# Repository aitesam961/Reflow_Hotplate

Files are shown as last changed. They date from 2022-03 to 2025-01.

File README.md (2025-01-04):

# Reflow_Hotplate

### Dear Community! 
Thanks for your interest in this project. We would like to inform you that we have noticed some bugs in the hardware part of this project. We cannot promise immediate support but we plan on fixing it as soon as we get time out of our living jobs. 
Appreciated 

<p align="center">
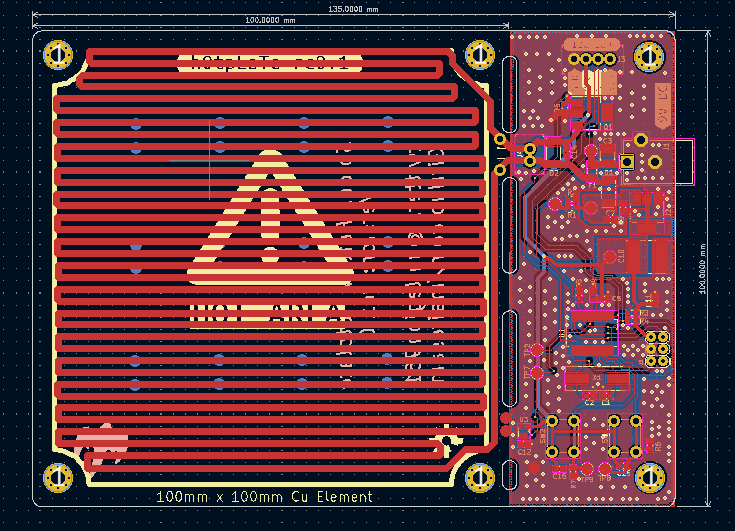
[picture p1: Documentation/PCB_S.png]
Opening Image
  
</p>
A reflow Hotplate for DIY SMD assembly.

## Introduction;
This device is created as a Low-Cost solution for DIY reflow assembly of SMD components. 

## Key Features:

* Compact Design
* 9V-12V DC Input via regular DC Jack 
* 100mm x 100mm Reflow area
* High-Current protection
* PIC16F MCU to control the system
* PIC programmer Interface
* I2C LCD Support
* Detachable design [See More](https://github.com/maitesam/Reflow_Hotplate/#detachable-design)
* Temperature Probs
* UI with LCD and Pushbuttons for controlling the system.
* Low Cost & Portable

<p align="center">
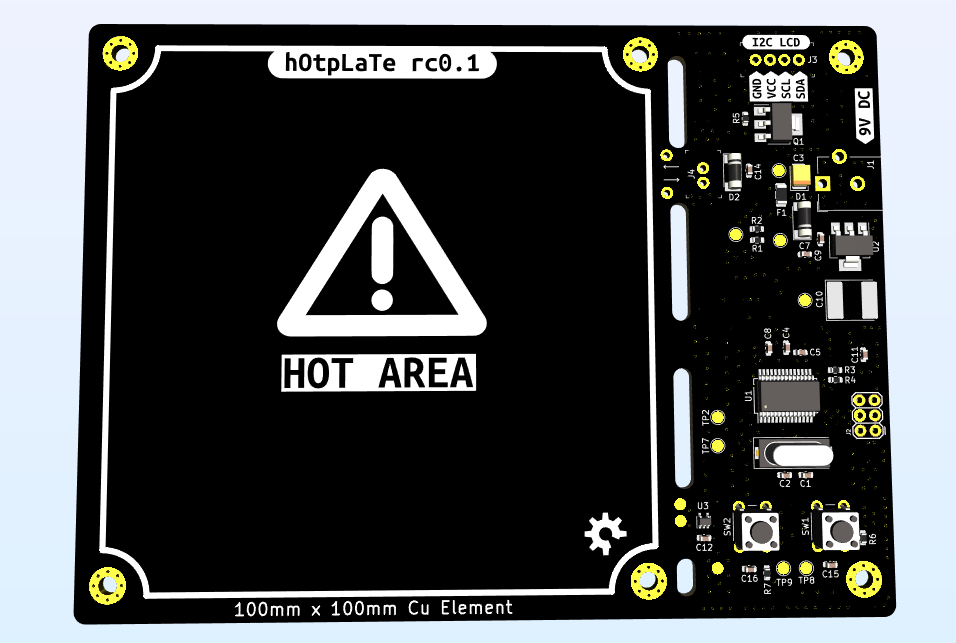
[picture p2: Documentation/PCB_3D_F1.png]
  
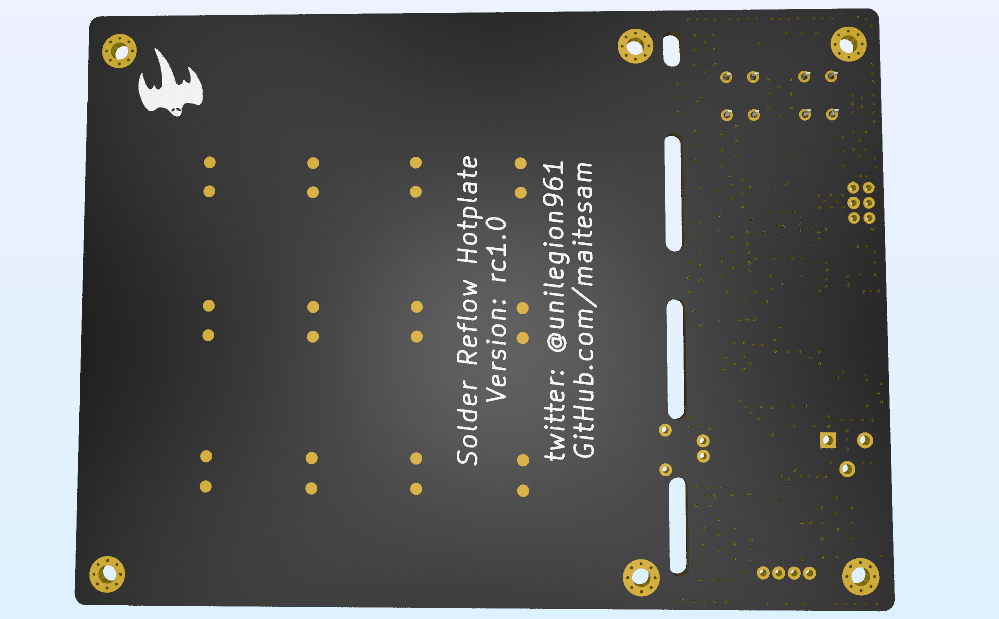
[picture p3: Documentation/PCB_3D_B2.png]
  
 
</p>

### What is Reflow Soldering?

Reflow soldering is a process in which a solder paste (a sticky mixture of powdered solder and flux) is used to temporarily attach one or thousands of tiny electrical components to their contact pads, after which the entire assembly is subjected to controlled heat. The solder paste reflows in a molten state, creating permanent solder joints. Heating may be accomplished by passing the assembly through a reflow oven.

[View more on Wikipedia](https://en.wikipedia.org/wiki/Reflow_soldering#:~:text=Reflow%20soldering%20is%20a%20process%20in%20which%20a,in%20a%20molten%20state%2C%20creating%20permanent%20solder%20joints)

### Reflow Curve
The reflow curve of the temperature of a certain point on the SMA with time when the SMA passes through the reflow oven furnace. The temperature curve provides an intuitive method to analyze the temperature change of a component during the entire reflow soldering process.
Below is the proper reflow curve a heater should achieve for perfect soldering of components.

The hOtpLaTe r0.1 manages to acheive this temperature curve by adjusting the switching duty of MOSFET which results in variation in heat.
The temperature sensor continously reads the temperatures and sends back to the Microcontroller.
<p align="center">
  Opening Image
</p>

### Detachable Design:
 This board is created considering all the potential issues and major use cases. The advantange is that you can use it either as a whole system by simply plugging the power in and starting the system
 OR
 You can detach the controller and Coil area of the PCB (separated by cut-lines).
 
 This makes it highly portable and Tweakers friendly.

 ### Why you may need to do this?
 The standard PCB material is FR4 which is very reliable in handling higher temperatures but it may not be very long lasting if being used very often.
 So, I came up with a backup plan and designed it in a way you can just cut the controller portion away from the coil area and use the controller with any OFF the SHELF heating element like alluminum plates.
 
 [Something Like This](https://www.aliexpress.com/item/1005003750400097.html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)

## Manufactruring Guidelines
You Can manufacture the PCBs from PCBWay.
[Check Out PCBWay](https://www.pcbway.com/setinvite.aspx?inviteid=440401)

Note: I am not affiliated with PCBWay. However, I just like their service and build quality.

## Assembly
It is super convenient to assemble the Hardware & Components specially if you ordered the Stencil alongwith PCBs.
After opening the Project in KiCAD, you can just scroll through the BOM and place components with respect to their designators.
OR
If you wish to order assembled PCBs, I optimized the BOM to make it super smooth and easy to source components. 
It is requested to please Open up an Issues if there is any stock outage or Manufacturing Problems.

## General Instructions
* Program the Microcontroller using CP210x/CH340x/FTDI based USB to serial converters.
* The ARDUINO IDE can be used to Program the Microcontroller.
* Power Up the Board using a PSU with 6-12V @ 2A Ratings.
*  Give Hotplate Enough time to Heatup and cooldown. Any Forced Cooldown solution is highly **NOT RECOMMENDED** as it reduces the Life of FR4 material.
* If Temperatures Higher than 270C are desired, feel free to breakdown/cutdown the Controller portion and Heating Element to avoid controller assembly meltdown. (In such case, desolder the Temperature sensor and extend it to the bottom of the hotplate using wires).

### Contributions

Contributions are what make the open source community such an amazing place to learn, inspire, and create. Any contributions you make are **greatly appreciated**.

If you have a suggestion that would make this better, please fork the repo and create a pull request. You can also simply open an issue with the tag "enhancement".
Don't forget to give the project a star! Thanks again!

1. Fork the Project
2. Create your Feature Branch (`git checkout -b feature/AmazingFeature`)
3. Commit your Changes (`git commit -m 'Add some AmazingFeature'`)
4. Push to the Branch (`git push origin feature/AmazingFeature`)
5. Open a Pull Request

## Roadmap
* [x] Proof of Concept
* [x] Research & Information
* [x] Finalizing The Idea
* [x] Schematics
* [x] PCB Design
* [x] Firmware Development
* [ ] Validation & Testing
* [x] Documentation
* [ ] Future Improvements

## Future Plans
This Hotplate is based on Regular FR4 materials that degrade over time due to excessive heating. In near future, it is desired to implement the same Idea on Alluminum Base PCBs. 
ISSUE: Alluminum would act as heatsink not letting the plate to heatup/quick cooldowns.
Community please step in.........

## License

This Project and information is published under General Public License V3.0 See `LICENSE.txt` for more information.
> https://www.gnu.org/licenses/quick-guide-gplv3.html

<p align="right">(<a href="#top">back to top</a>)</p>

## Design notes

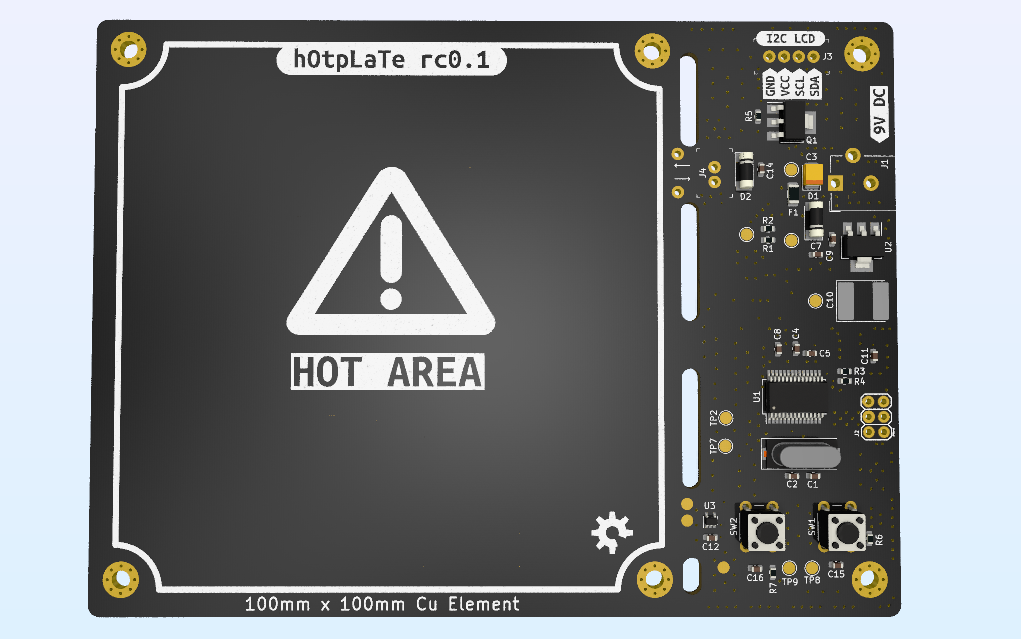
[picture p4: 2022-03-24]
Documentation/PCB_3D_F3.png

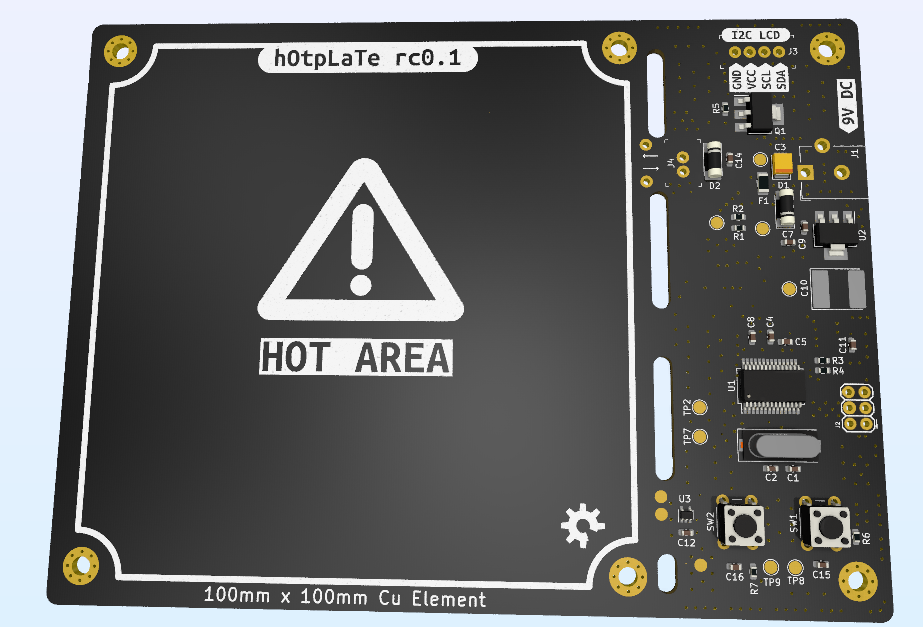
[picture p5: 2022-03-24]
Documentation/PCB_3D_F2.png

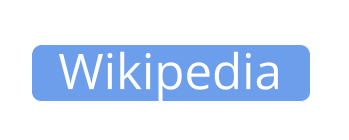
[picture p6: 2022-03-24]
Documentation/WIkipedia Button (1).png

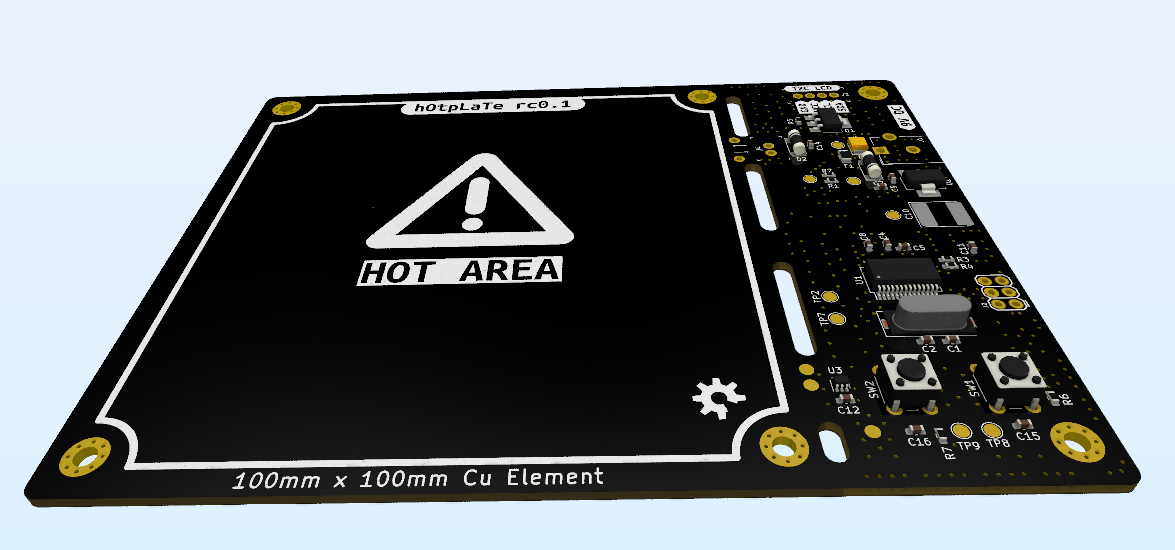
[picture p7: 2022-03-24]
Documentation/PCB_3D_F4.png

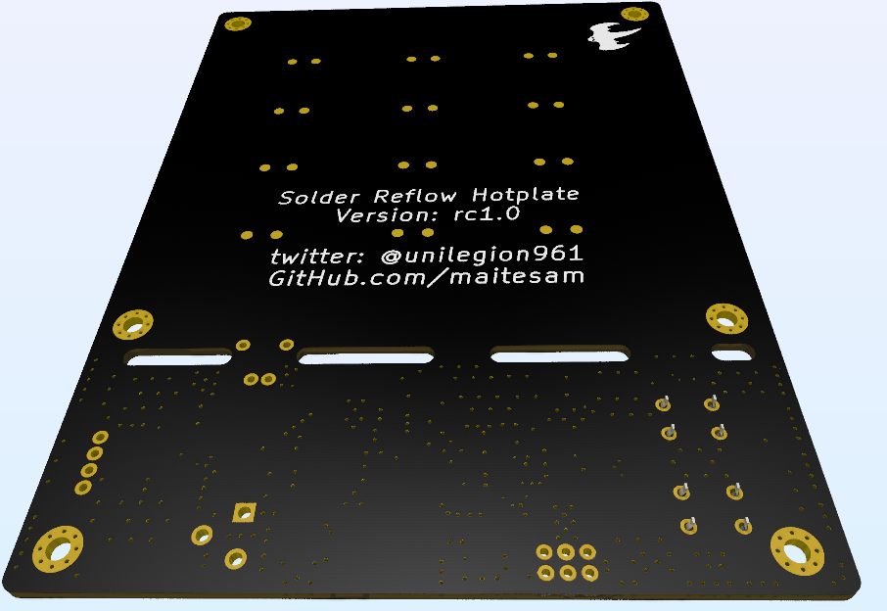
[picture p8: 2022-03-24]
Documentation/PCB_3D_B1.png

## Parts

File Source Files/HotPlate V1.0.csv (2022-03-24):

Source: | C:\Users\aites\Documents\KiCad\HotPlate V1.0\HotPlate V1.0.kicad_sch
Date: | 3/24/2022 1:29:14 AM
Tool: | Eeschema (6.0.4)
Generator: | D:\D_Program Files\6.0\bin\scripting\plugins/bom_csv_grouped_by_value_with_fp.py
Component Count: | 43
Ref | Qnty | Value | Cmp name | Footprint | Description | Vendor
C1, C2, C5, C8, C11, C12, C14, C15, C16, | 9 | 100nF | C_Small | Capacitor_SMD:C_0603_1608Metric | Unpolarized capacitor, small symbol
C3, | 1 | 10uF | C_Polarized_Small_US | Capacitor_Tantalum_SMD:CP_EIA-3528-12_Kemet-T | Polarized capacitor, small US symbol
C4, C7, C9, | 3 | 1uF | C_Small | Capacitor_SMD:C_0603_1608Metric | Unpolarized capacitor, small symbol
C10, | 1 | 22uF | C_Small | Capacitor_Tantalum_SMD:CP_EIA-7260-28_AVX-M_Pad2.68x6.30mm_HandSolder | Unpolarized capacitor, small symbol
D1, D2, | 2 | 1N5711UR | 1N5711UR | Diode_SMD:D_MELF | 70V 33mA Schottky diode, MELF(DO-213AA)
F1, | 1 | 2A | Fuse | Fuse:Fuse_1206_3216Metric | Fuse
J1, | 1 | Jack-DC | Jack-DC | Connector_BarrelJack:BarrelJack_CUI_PJ-102AH_Horizontal | DC Barrel Jack
J2, | 1 | CONN_03X22X3_SILK_MALE_PTH | CONN_03X22X3_SILK_MALE_PTH | Connectors:2X3 | Multi connection point. Often used as Generic Header-pin footprint for 0.1 inch spaced/style header connections <b>You can populate with any combo of single row headers, but if you'd like an exact match, check these:</b><ul><li><a href="https://www.sparkfun.com/products/12807"> Header - 2x3 (Male, 0.1")</a> (PRT-12807)</li><li><a href="https://www.sparkfun.com/products/13010"> Header - 2x3 (Female, 0.1")</a> (PRT-13010)</li><li><a href="https://www.sparkfun.com/products/10877"> 2x3 Pin Shrouded Header</a> (PRT-10877)</li></ul> <b>On any of the 0.1 inch spaced packages, you can populate with these:</b><ul><li><a href="https://www.sparkfun.com/products/116"> Break Away Headers - Straight</a> (PRT-00116)</li><li><a href="https://www.sparkfun.com/products/553"> Break Away Male Headers - Right Angle</a> (PRT-00553)</li><li><a href="https://www.sparkfun.com/products/115"> Female Headers</a> (PRT-00115)</li><li><a href="https://www.sparkfun.com/products/117"> Break Away Headers - Machine Pin</a> (PRT-00117)</li><li><a href="https://www.sparkfun.com/products/743"> Break Away Female Headers - Swiss Machine Pin</a> (PRT-00743)</li></ul> <b>Special note: the shrouded connector mates well with our 3x2 ribbon cables:</b><ul><li><a href="https://www.sparkfun.com/products/10651"> Ribbon Crimp Connector - 6-pin (2x3, Female)</a> (PRT-10651)</li><li><a href="https://www.sparkfun.com/products/10646"> Ribbon Cable - 6 wire (15ft)</a> (PRT-10646)</li></ul>
J3, | 1 | B4B-XH-A_LF__SN_ | B4B-XH-A_LF__SN_ | digikey-footprints:PinHeader_1x4_P2.5mm_Drill1.1mm | CONN HEADER VERT 4POS 2.5MM
J4, | 1 | B2B-XH-A_LF__SN_ | B2B-XH-A_LF__SN_ | digikey-footprints:PinHeader_1x2_P2.5mm_Drill1.1mm | CONN HEADER VERT 2POS 2.5MM
Q1, | 1 | DMG1012T | DMG1012T | Package_TO_SOT_SMD:SOT-223 | 20V Vds, 0.63 Id, N-Channel MOSFET with ESD protection, SOT-523
R1, | 1 | 3k | R_Small | Resistor_SMD:R_0603_1608Metric | Resistor, small symbol
R2, | 1 | 1k | R_Small | Resistor_SMD:R_0603_1608Metric | Resistor, small symbol
R3, R4, R5, R6, R7, | 5 | 10k | R_Small | Resistor_SMD:R_0603_1608Metric | Resistor, small symbol
SW1, SW2, | 2 | SW_Push | SW_Push | Button_Switch_THT:SW_PUSH_6mm | Push button switch, generic, two pins
TP1, TP2, TP3, TP4, TP6, TP7, TP8, TP9, | 8 | TestPoint | TestPoint | TestPoint:TestPoint_Pad_D2.0mm | test point
U1, | 1 | PIC16F1512-ISS | PIC16F1512-ISS | Package_SO:SSOP-28_5.3x10.2mm_P0.65mm | PIC16F1512, 2048W FLASH, 128B SRAM, SSOP-28
U2, | 1 | AMS1117-5.0 | AMS1117-5.0 | Package_TO_SOT_SMD:SOT-223-3_TabPin2 | 1A Low Dropout regulator, positive, 5.0V fixed output, SOT-223
U3, | 1 | LMT85DCK | LMT85DCK | Package_TO_SOT_SMD:SOT-353_SC-70-5 | Analog temperature sensor, NTC, 0.3C accuracy, -8.2mV/C, -50C to +150C, 1.8 to 5.5V, SC-70-5
X1, | 1 | 16MHz | Crystal | Crystal:Crystal_SMD_HC49-SD | Two pin crystal

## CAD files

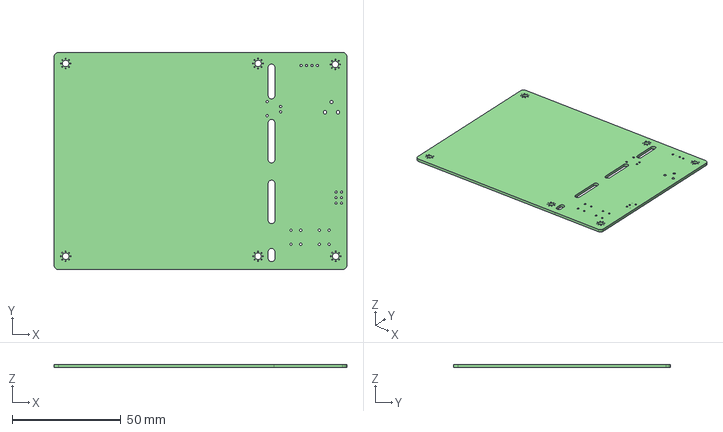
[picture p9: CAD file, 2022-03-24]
Manufacturing Files/HotPlate V1.0.step
135.0 x 100.0 x 1.60 mm

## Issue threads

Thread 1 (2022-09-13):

Power transitor issues (Q1)

saper-2, 2022-09-13:
I have basically 2 things to point out aroung Q1:

1. DMG1012T is in SOT-523 footprint, not in SOT-223 , 👉  fix P/N in schematic.
2. SOT-223 pin 4 "tab" should be connected to GND too, and around there should be some via for thermal dissipation to both GND zones.

aitesam961, 2022-09-13:
Eagle Eye Spotting.
Will work on fixing it soon.

aitesam961, 2022-09-13:
Invalid

Triton2020, 2022-11-27:
Hi, what is the Stand for this Fix ? I see no change on the PCB layout, what means your respond on thios Problem "Invalid" ???????

Triton2020, 2022-12-03:
It is not realy a Hint "check Source File" please can you explain what is the point ????

arrowsmashing, 2023-05-04:
Is there a recomended replacement part for Q1, have a DMG1012T-7, but it is too small to fit the pads?

Closed 2022-09-13.

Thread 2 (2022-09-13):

Thermal relief on pads connected to zone

saper-2, 2022-09-13:
Hi,

You don't have thermal relief on pads that connect to GND zone(s). It make much harder to solder parts, especially when it's not needed in 99,9% of them to have direct-connect style. Only in Q1 it desirable to use direct-connect style. In others parts not really. For small part 10-20mils wide, and 10mils margin from pad is fine. For e.g. components "bigger" like electrolytic capacitors or power jack 20-30mils width (10mils spacing too) should be fine in this circuit.

aitesam961, 2022-09-13:
Invalid

Closed 2022-09-13.

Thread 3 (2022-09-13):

Other suggestions

saper-2, 2022-09-13:
And few other suggestions 😄

1. When drawing slots for milling it's easier for fab just by drawing a line (track) on mechanical layer (that have width of mill bit diameter (mostly common bit sizes used by fab house have: 2mm and 3mm ) , so there is no need for wasting time to draw outline 😉 .
I use some User..... layer for this, and also I draw one in margin-layer (edge.cuts). Of course I leave note for fab house that on this layer is mill drawing.
2. U3 is a bit in unfortunate place 😉 , it's not directly on hot-plate section , and it "cooled down" by GND zones... since you're have milling already maybe think about something to make it "separable" in case if someone decide to brake apart board into control and hot-plate part. maybe mill a bit around it (using 2mm bit?) so more heat transfer from hot-plate part, and will be cooled less by control-circuit-part
3. Have you considered creating hot-plate using MCPCB (pcb aluminum , like the one used in power-led modules as radiator 😄 ). And I see JLC have rather acceptable price for it too.

aitesam961, 2022-09-13:
Invalid

Closed 2022-09-13.

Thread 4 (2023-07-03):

Arduino IDE

arrowsmashing, 2023-07-03:
Could you give some hints on the settings to use in Arduino IDE to upload the arduino.h to the PIC? E.g. what board to use in the settings?

aitesam961, 2023-07-09:
You can follow this guide on Instructables
https://www.instructables.com/how-to-program-a-PIC-18F2550-or-18f4550-with-Ardui/
BTW, I'd like to inform that I have noticed minor issues with hardware design of this project recently.  I cannot promise immediate solution but I will redesign this project once I get out of my extremely busy work routine.

Closed 2023-09-15.

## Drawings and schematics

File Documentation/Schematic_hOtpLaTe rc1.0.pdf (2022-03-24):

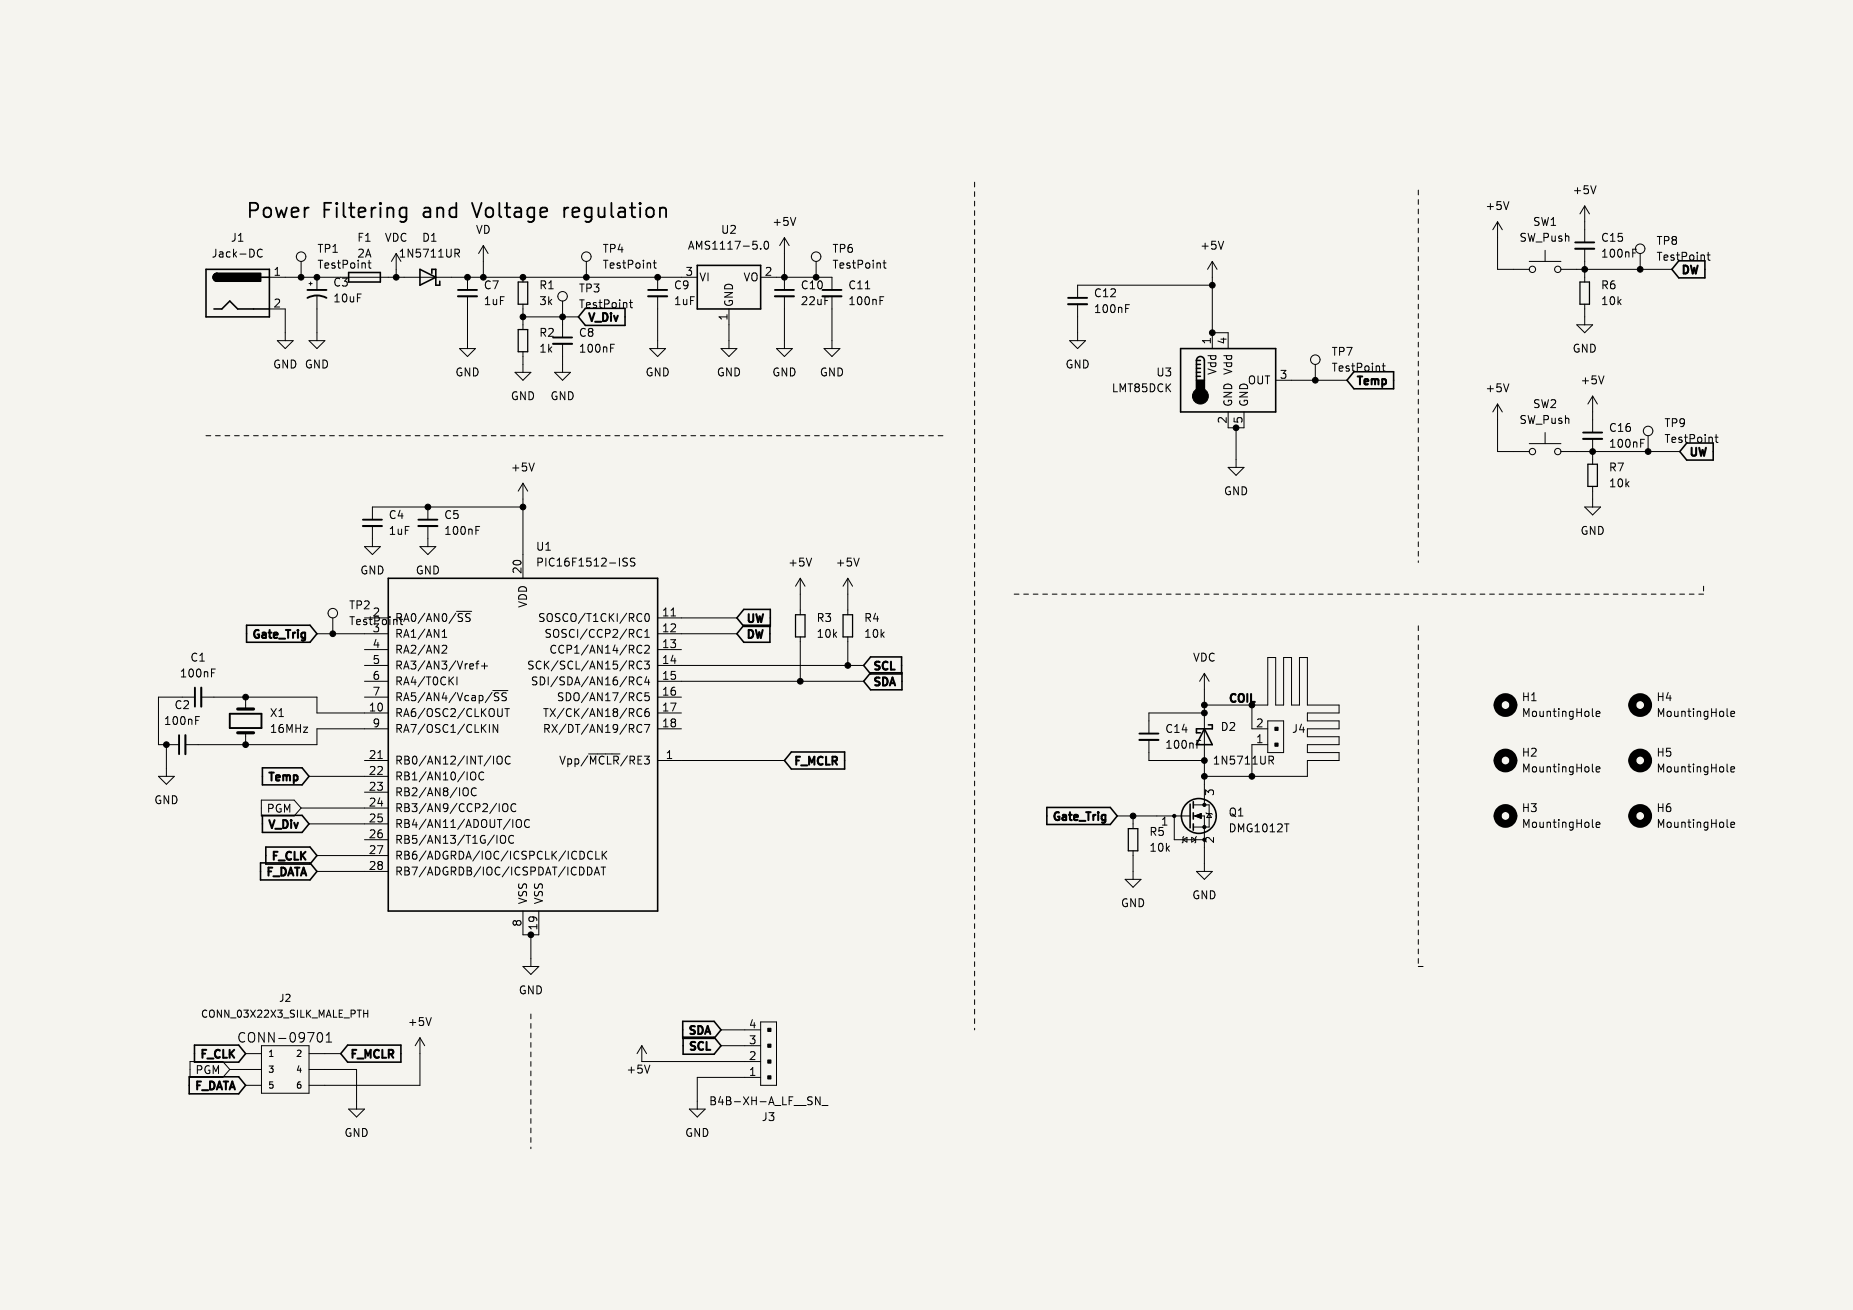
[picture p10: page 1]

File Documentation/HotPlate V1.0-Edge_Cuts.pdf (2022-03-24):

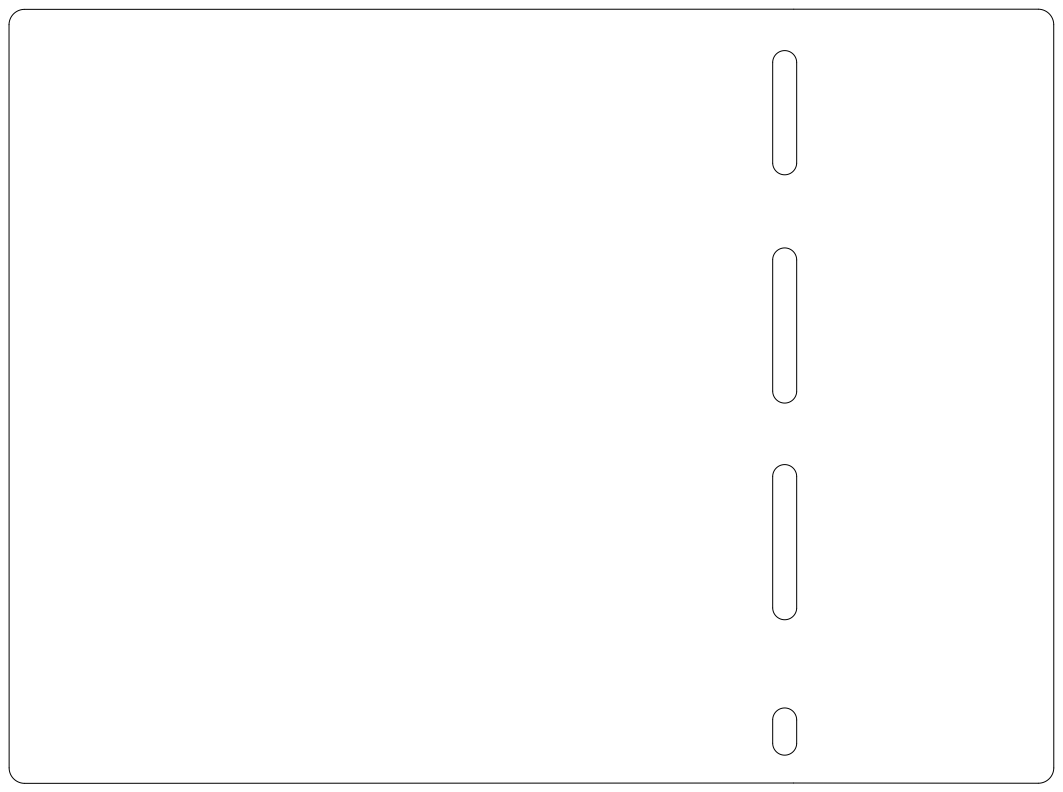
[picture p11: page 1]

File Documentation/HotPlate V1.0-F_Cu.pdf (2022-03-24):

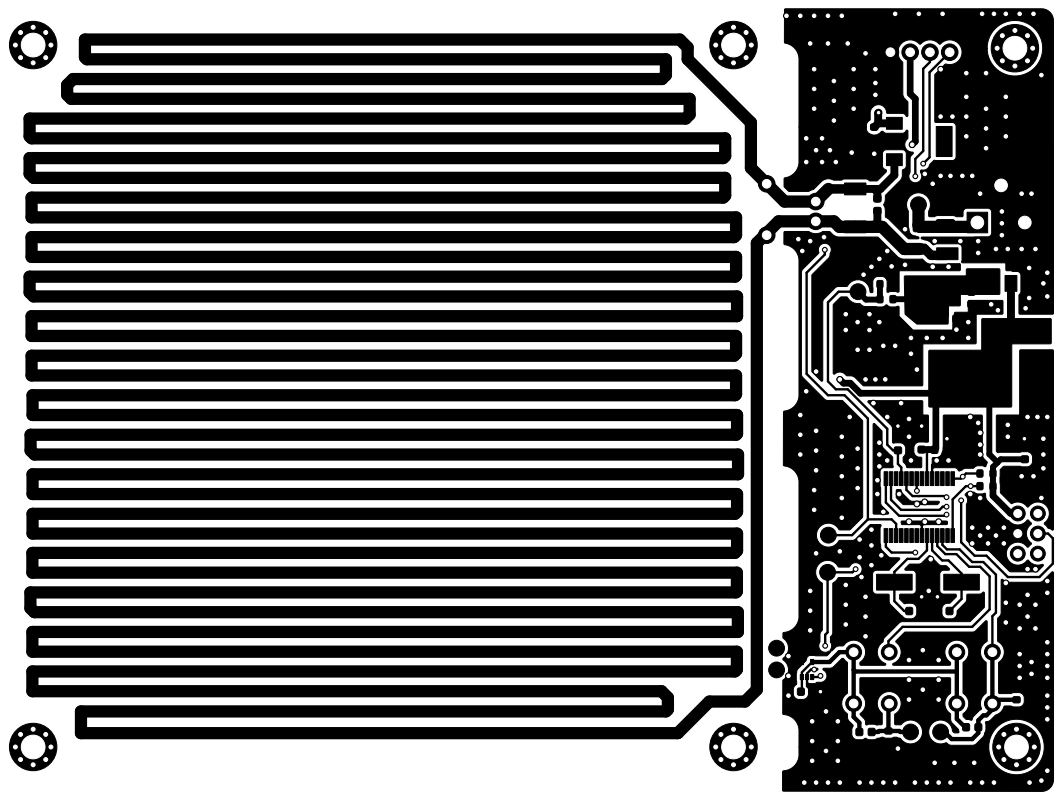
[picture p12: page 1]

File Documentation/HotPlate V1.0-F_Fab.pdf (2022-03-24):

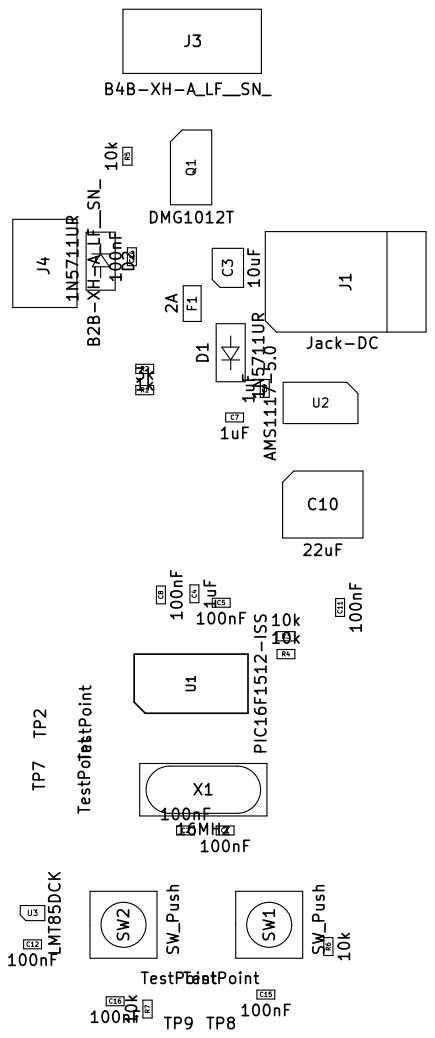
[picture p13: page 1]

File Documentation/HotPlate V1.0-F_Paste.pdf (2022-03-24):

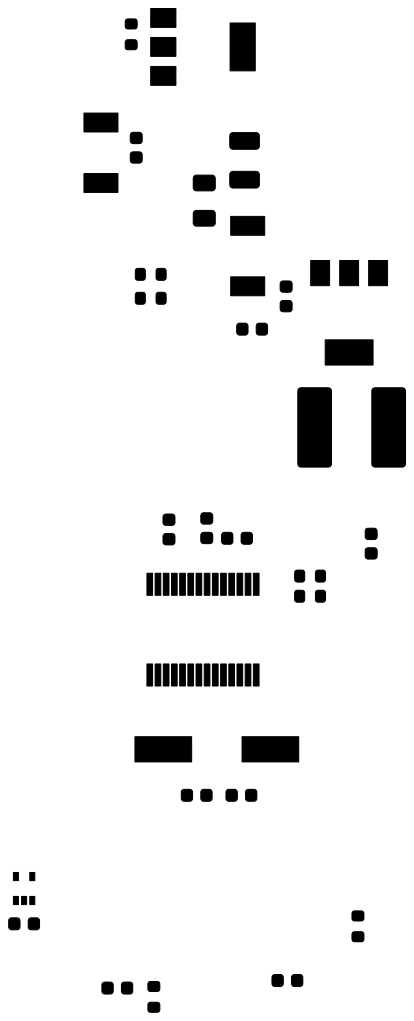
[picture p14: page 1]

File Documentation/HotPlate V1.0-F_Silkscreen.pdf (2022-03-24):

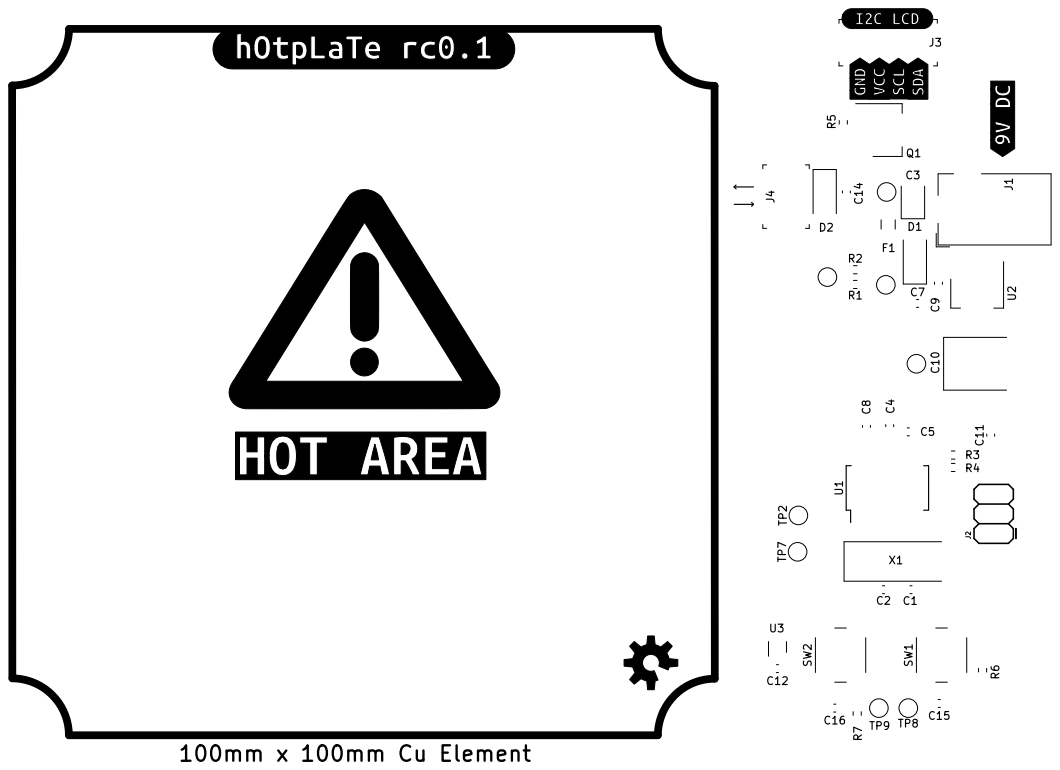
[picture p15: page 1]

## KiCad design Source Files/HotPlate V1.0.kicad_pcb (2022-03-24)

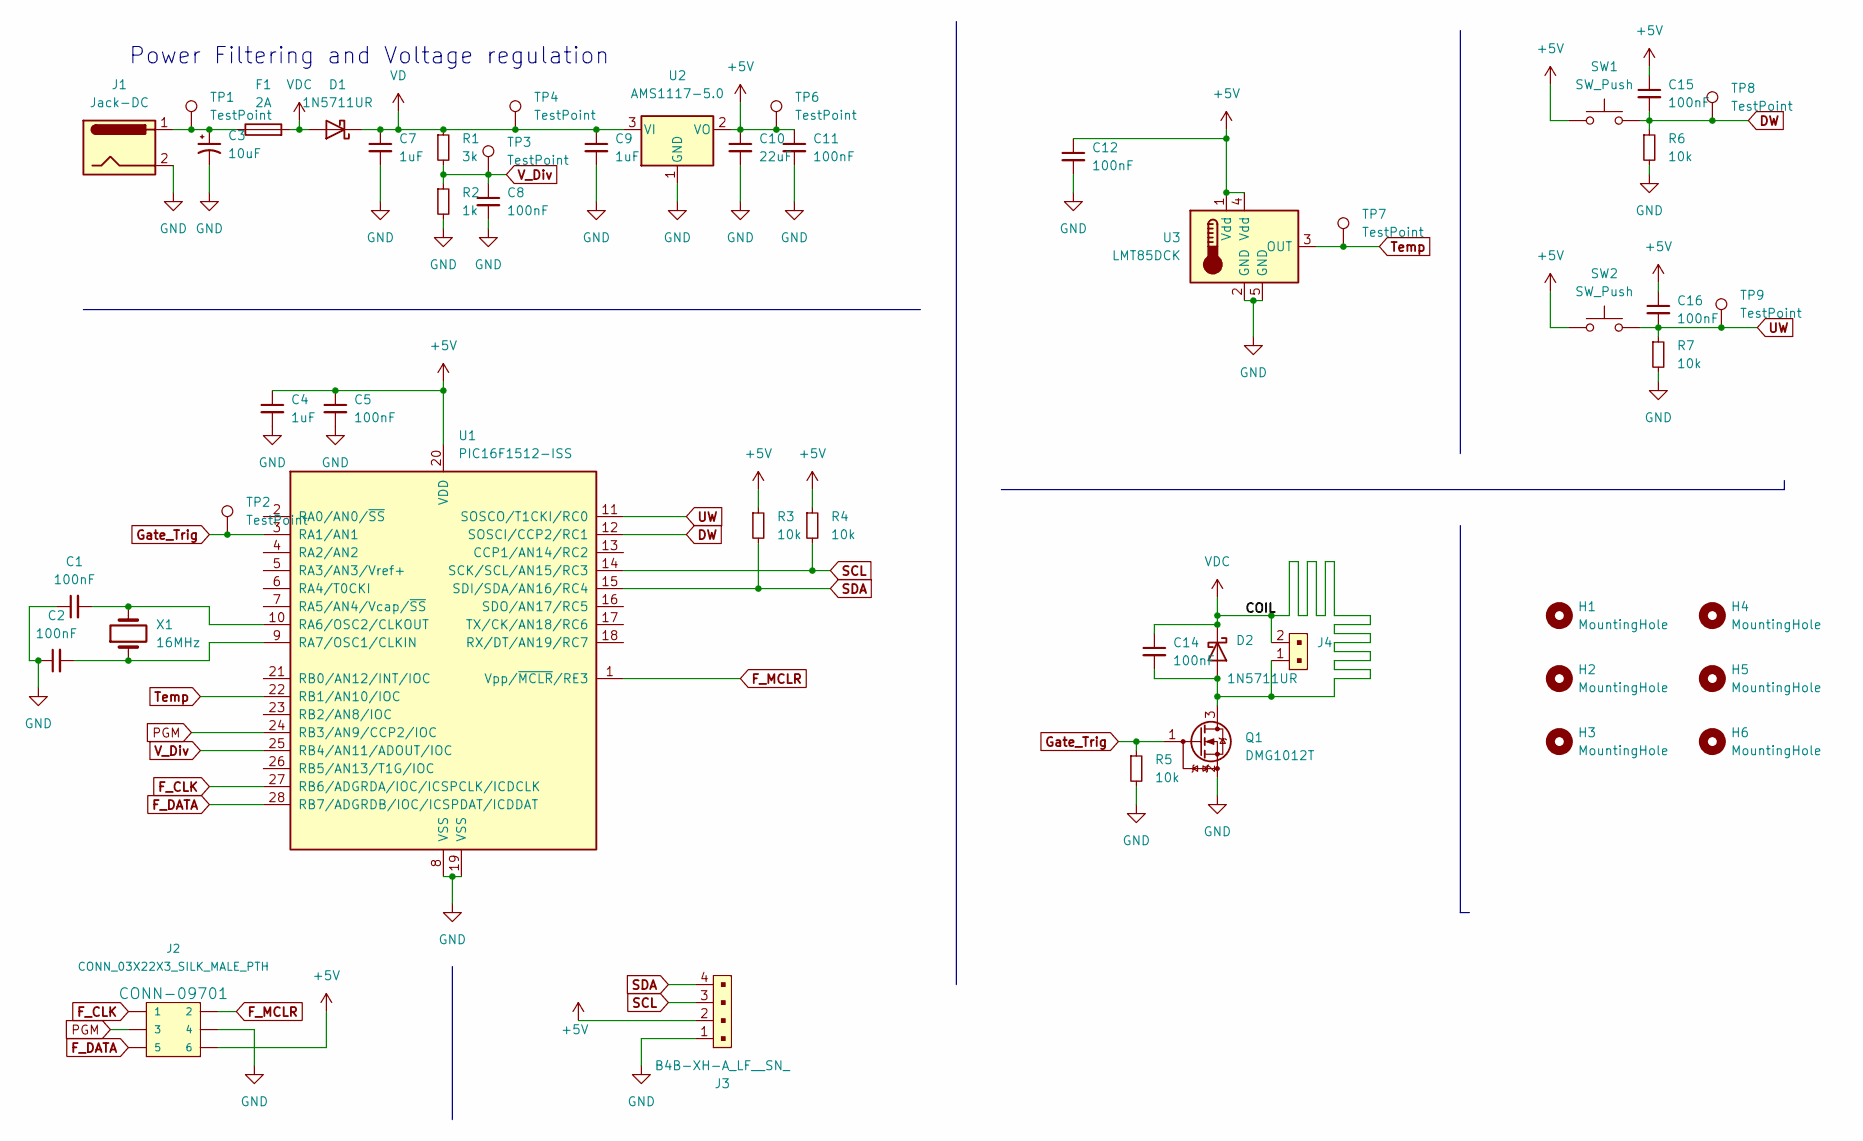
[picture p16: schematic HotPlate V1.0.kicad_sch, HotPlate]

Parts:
C1, C2, C5, C8, C11, C12, C14, C15, C16: 100nF; C_0603_1608Metric
C3: 10uF; CP_EIA-3528-12_Kemet-T
C4, C7, C9: 1uF; C_0603_1608Metric
C10: 22uF; CP_EIA-7260-28_AVX-M_Pad2.68x6.30mm_HandSolder
D1, D2: 1N5711UR; D_MELF
F1: 2A; Fuse_1206_3216Metric
H1, H2, H3, H4, H5, H6: MountingHole; MountingHole_3mm_Pad_Via
J1: Jack-DC; BarrelJack_CUI_PJ-102AH_Horizontal
J2: CONN_03X22X3_SILK_MALE_PTH; 2X3
J3: B4B-XH-A_LF__SN_; PinHeader_1x4_P2.5mm_Drill1.1mm; MPN B4B-XH-A(LF)(SN); Digi-Key_PN 455-2249-ND
J4: B2B-XH-A_LF__SN_; PinHeader_1x2_P2.5mm_Drill1.1mm; MPN B2B-XH-A(LF)(SN); Digi-Key_PN 455-2247-ND
Q1: DMG1012T; SOT-223
R1: 3k; R_0603_1608Metric
R2: 1k; R_0603_1608Metric
R3, R4, R5, R6, R7: 10k; R_0603_1608Metric
SW1, SW2: SW_Push; SW_PUSH_6mm
TP1, TP2, TP3, TP4, TP6, TP7, TP8, TP9: TestPoint; TestPoint_Pad_D2.0mm
U1: PIC16F1512-ISS; SSOP-28_5.3x10.2mm_P0.65mm
U2: AMS1117-5.0; SOT-223-3_TabPin2
U3: LMT85DCK; SOT-353_SC-70-5
X1: 16MHz; Crystal_SMD_HC49-SD

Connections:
+5V: C4.1, C5.1, C10.1, C11.1, C12.1, C15.1, C16.1, J2.6, J3.2, R3.1, R4.1, SW1.1, SW2.1, TP6.1, U1.20 (VDD), U2.2 (VO), U3.1 (Vdd), U3.4 (Vdd)
DW: C15.2, R6.1, SW1.2, TP8.1, U1.12 (SOSCI/CCP2/RC1)
F_CLK: J2.1, U1.27 (RB6/ADGRDA/IOC/ICSPCLK/ICDCLK)
F_DATA: J2.5, U1.28 (RB7/ADGRDB/IOC/ICSPDAT/ICDDAT)
F_MCLR: J2.2, U1.1 (Vpp/~MCLR/RE3)
GND: C1.1, C2.1, C3.2, C4.2, C5.2, C7.2, C8.2, C9.2, C10.2, C11.2, C12.2, J1.2, J1.3, J2.4, J3.1, Q1.2 (S), R2.2, R5.2, R6.2, R7.2, U1.8 (VSS), U1.19 (VSS), U2.1 (GND), U3.2 (GND), U3.5 (GND)
Gate_Trig: Q1.1 (G), R5.1, TP2.1, U1.3 (RA1/AN1)
unnamed: C1.2, U1.10 (RA6/OSC2/CLKOUT), X1.2
unnamed: C2.2, U1.9 (RA7/OSC1/CLKIN), X1.1
unnamed: C3.1, F1.1, J1.1, TP1.1
PGM: J2.3, U1.24 (RB3/AN9/CCP2/IOC)
SCL: J3.3, R4.2, U1.14 (SCK/SCL/AN15/RC3)
SDA: J3.4, R3.2, U1.15 (SDI/SDA/AN16/RC4)
Temp: TP7.1, U1.22 (RB1/AN10/IOC), U3.3 (OUT)
UW: C16.2, R7.1, SW2.2, TP9.1, U1.11 (SOSCO/T1CKI/RC0)
VD: C7.1, C9.1, D1.1 (K), R1.1, TP4.1, U2.3 (VI)
VDC: C14.1, C14.2, D1.2 (A), D2.1 (K), D2.2 (A), F1.2, J4.1, J4.2, Q1.3 (D)
V_Div: C8.1, R1.2, R2.1, TP3.1, U1.25 (RB4/AN11/ADOUT/IOC)

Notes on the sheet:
Power Filtering and Voltage regulation

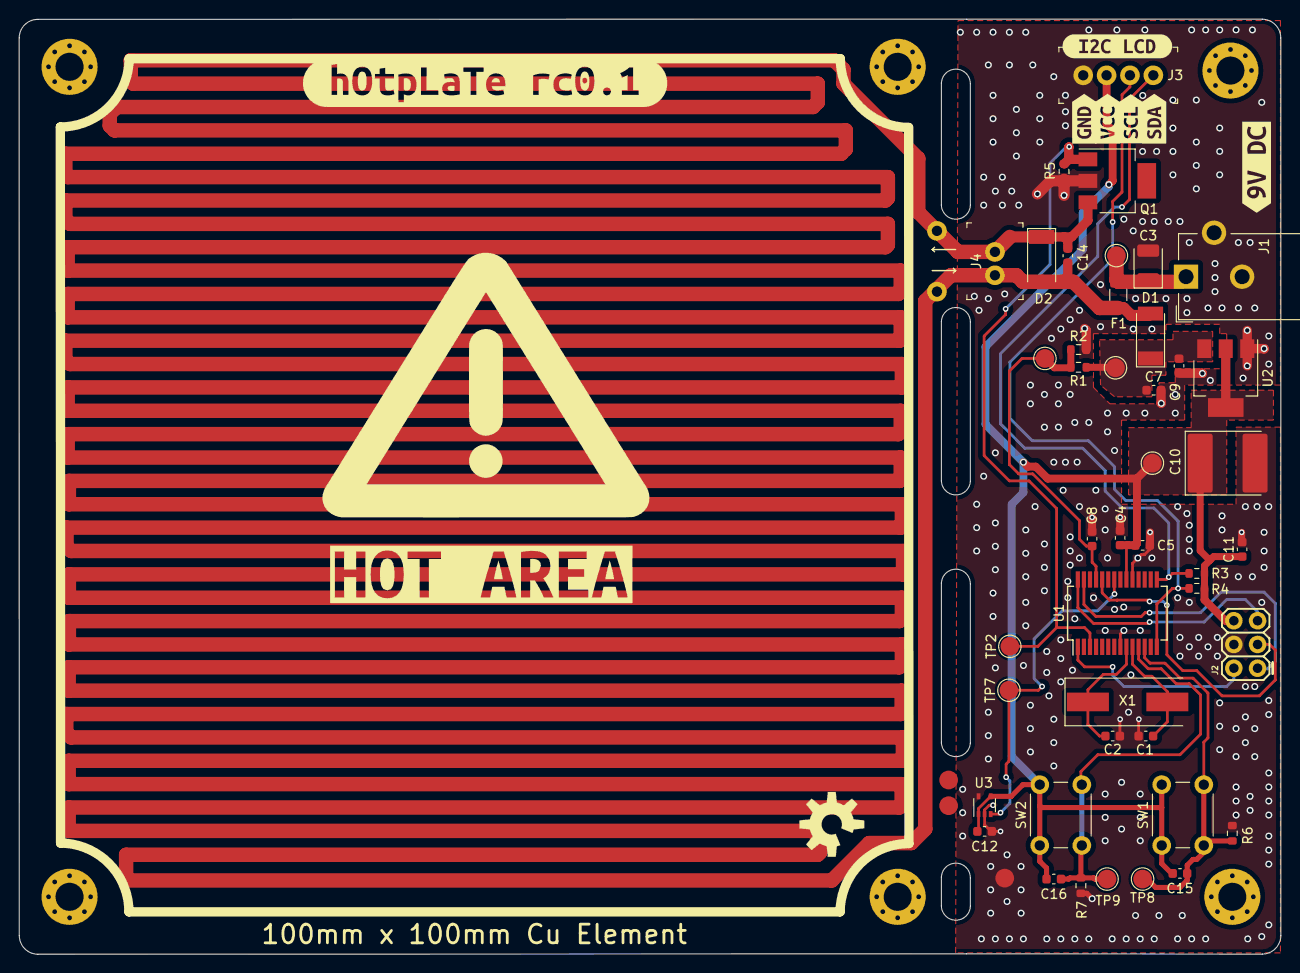
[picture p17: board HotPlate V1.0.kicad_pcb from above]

Board: 2 copper layers, 135.0 x 100.0 mm, 57 parts (0 on the bottom side), 18 nets.

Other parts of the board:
kibuzzard-623AE740: G***; kibuzzard-623AE740
kibuzzard-623AF188: G***; kibuzzard-623AF188
kibuzzard-623B16D9: G***; kibuzzard-623B16D9
kibuzzard-623B16F0: G***; kibuzzard-623B16F0
kibuzzard-623B170E: G***; kibuzzard-623B170E
kibuzzard-623B171E: G***; kibuzzard-623B171E
kibuzzard-623B196E: G***; kibuzzard-623B196E
kibuzzard-623C18C2: G***; kibuzzard-623C18C2

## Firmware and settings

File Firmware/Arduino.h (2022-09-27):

#include <thermistor.h>             //Downlaod it here: http://electronoobs.com/eng_arduino_thermistor.php
thermistor therm1(A0,0);            //The 3950 Thermistor conencted on A0 
//LCD config
#include <Wire.h>                   //Included by Arduino IDE
#include <LiquidCrystal_I2C.h>      //Downlaod it here: http://electronoobs.com/eng_arduino_liq_crystal.php
LiquidCrystal_I2C lcd(0x27,16,2);   //Define LCD address as 0x27. Also try 0x3f if it doesn't work. 

//Inputs and Outputs
int but_1 = 12;
int but_2 = 11;
int but_3 = 10; 
int but_4 = 9;
int SSR = 3;
int buzzer = 6;
int Thermistor_PIN = A0;

//Variables
unsigned int millis_before, millis_before_2;    //We use these to create the loop refresh rate
unsigned int millis_now = 0;
float refresh_rate = 500;                       //LCD refresh rate. You can change this if you want
float pid_refresh_rate  = 50;                   //PID Refresh rate
float seconds = 0;                              //Variable used to store the elapsed time                   
int running_mode = 0;                           //We store the running selected mode here
int selected_mode = 0;                          //Selected mode for the menu
int max_modes = 3;                              //For now, we only work with 1 mode...
bool but_3_state = true;                        //Store the state of the button (HIGH OR LOW)
bool but_4_state  =true;                        //Store the state of the button (HIGH OR LOW)
float temperature = 0;                          //Store the temperature value here
float preheat_setoint = 140;                    //Mode 1 preheat ramp value is 140-150ºC
float soak_setoint = 150;                       //Mode 1 soak is 150ºC for a few seconds
float reflow_setpoint = 200;                    //Mode 1 reflow peak is 200ºC
float temp_setpoint = 0;                        //Used for PID control
float pwm_value = 255;                          //The SSR is OFF with HIGH, so 255 PWM would turn OFF the SSR
float MIN_PID_VALUE = 0;
float MAX_PID_VALUE = 180;                      //Max PID value. You can change this. 
float cooldown_temp = 40;                       //When is ok to touch the plate

/////////////////////PID VARIABLES///////////////////////
/////////////////////////////////////////////////////////
float Kp = 2;               //Mine was 2
float Ki = 0.0025;          //Mine was 0.0025
float Kd = 9;               //Mine was 9
float PID_Output = 0;
float PID_P, PID_I, PID_D;
float PID_ERROR, PREV_ERROR;
/////////////////////////////////////////////////////////

void setup() {
  //Define the pins as outputs or inputs
  pinMode(SSR, OUTPUT);
  digitalWrite(SSR, HIGH);        //Make sure we start with the SSR OFF (is off with HIGH)
  pinMode(buzzer, OUTPUT); 
  digitalWrite(buzzer, LOW);  
  pinMode(but_1, INPUT_PULLUP);
  pinMode(but_2, INPUT_PULLUP);
  pinMode(but_3, INPUT_PULLUP);
  pinMode(but_4, INPUT_PULLUP);
  pinMode(Thermistor_PIN, INPUT);

  lcd.init();                     //Init the LCD
  lcd.noBacklight();              //Activate backlight   
  Serial.begin(9600);
  tone(buzzer, 1800, 200);     
  millis_before = millis();
  millis_now = millis();
}

void loop() {
  millis_now = millis();
  if(millis_now - millis_before_2 > pid_refresh_rate){    //Refresh rate of the PID
    millis_before_2 = millis(); 
    
    temperature = therm1.analog2temp();
    
    if(running_mode == 1){   
      if(temperature < preheat_setoint){
        temp_setpoint = seconds*1.666;                    //Reach 150ºC till 90s (150/90=1.666)
      }  
        
      if(temperature > preheat_setoint && seconds < 90){
        temp_setpoint = soak_setoint;               
      }   
        
      else if(seconds > 90 && seconds < 110){
        temp_setpoint = reflow_setpoint;                 
      } 
       
      //Calculate PID
      PID_ERROR = temp_setpoint - temperature;
      PID_P = Kp*PID_ERROR;
      PID_I = PID_I+(Ki*PID_ERROR);      
      PID_D = Kd * (PID_ERROR-PREV_ERROR);
      PID_Output = PID_P + PID_I + PID_D;
      //Define maximun PID values
      if(PID_Output > MAX_PID_VALUE){
        PID_Output = MAX_PID_VALUE;
      }
      else if (PID_Output < MIN_PID_VALUE){
        PID_Output = MIN_PID_VALUE;
      }
      //Since the SSR is ON with LOW, we invert the pwm singal
      pwm_value = 255 - PID_Output;
      
      analogWrite(SSR,pwm_value);           //We change the Duty Cycle applied to the SSR
      
      PREV_ERROR = PID_ERROR;
      
      if(seconds > 130){
        digitalWrite(SSR, HIGH);            //With HIGH the SSR is OFF
        temp_setpoint = 0;
        running_mode = 10;                  //Cooldown mode        
      }     
    }//End of running_mode = 1


    //Mode 10 is between reflow and cooldown
    if(running_mode == 10){
      lcd.clear();
      lcd.setCursor(0,1);     
      lcd.print("    COMPLETE    ");
      tone(buzzer, 1800, 1000);    
      seconds = 0;              //Reset timer
      running_mode = 11;
      delay(3000);
    }    
  }//End of > millis_before_2 (Refresh rate of the PID code)
  

  
  millis_now = millis();
  if(millis_now - millis_before > refresh_rate){          //Refresh rate of prntiong on the LCD
    millis_before = millis();   
    seconds = seconds + (refresh_rate/1000);              //We count time in seconds
    

    //Mode 0 is with SSR OFF (we can selcet mode with buttons)
    if(running_mode == 0){ 
      digitalWrite(SSR, HIGH);        //With HIGH the SSR is OFF
      lcd.clear();
      lcd.setCursor(0,0);     
      lcd.print("T: ");
      lcd.print(temperature,1);   
      lcd.setCursor(9,0);      
      lcd.print("SSR OFF"); 
       
      lcd.setCursor(0,1);  
      if(selected_mode == 0){
        lcd.print("Select Mode");     
      }
      else if(selected_mode == 1){
        lcd.print("MODE 1");     
      }
      else if(selected_mode == 2){
        lcd.print("MODE 2");     
      }
      else if(selected_mode == 3){
        lcd.print("MODE 3");     
      }
      
      
    }//End of running_mode = 0

     //Mode 11 is cooldown. SSR is OFF
     else if(running_mode == 11){ 
      if(temperature < cooldown_temp){
        running_mode = 0; 
        tone(buzzer, 1000, 100); 
      }
      digitalWrite(SSR, HIGH);        //With HIGH the SSR is OFF 
      lcd.clear();
      lcd.setCursor(0,0);     
      lcd.print("T: ");
      lcd.print(temperature,1);   
      lcd.setCursor(9,0);      
      lcd.print("SSR OFF"); 
       
      lcd.setCursor(0,1);       
      lcd.print("    COOLDOWN    ");  
    }//end of running_mode == 11
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
